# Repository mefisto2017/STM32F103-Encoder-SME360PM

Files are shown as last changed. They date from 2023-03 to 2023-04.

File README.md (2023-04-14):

# STM32F103-Encoder-SME360PM

> __Warning__
 Crystal oscilator pins are not connected, working on the fix!

## About The Project
The code and board schematic were designed to read 4 absolute encoders SME360PM of a 4 wheel independent steering robot and transmit the values through CAN interface. The values are read in continous mode and organized using DMA. The board is based on the STM32F103 blue pill.

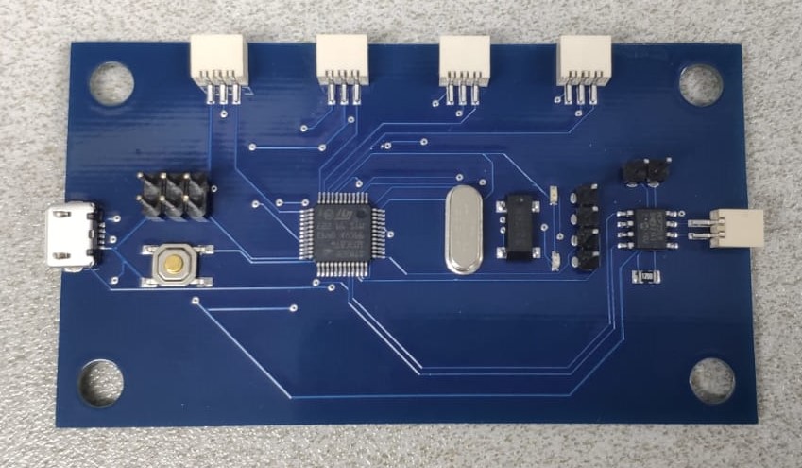
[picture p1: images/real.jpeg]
This is an image


## Getting Started

1. To request the values the following message must be send:
```sh
  [0x01, 0x00, 0x00, 0x00, 0x42, 0x1, 0x00, 0x00, 0x00, 0x00, 0x00, 0x00, 0x00]
```

2. The python script can be use to read and decode the angles 
```sh
  python3 Python_test_code/test.py
```

## Schematic Files
Schematic and gerber were generated on Eagle.

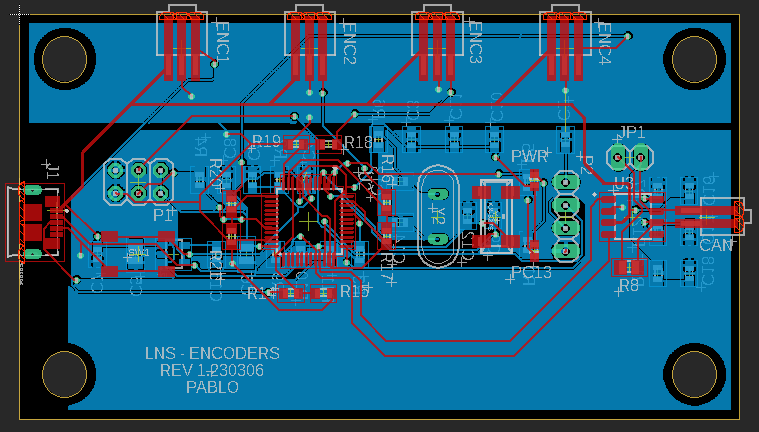
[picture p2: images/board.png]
This is an image


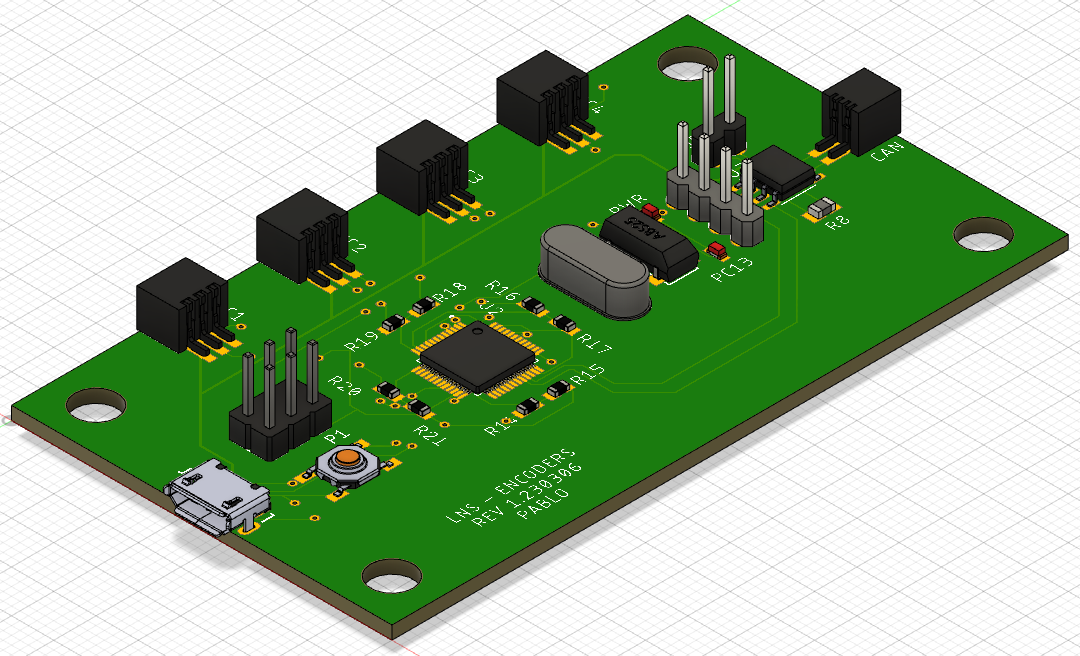
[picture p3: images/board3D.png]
This is an image


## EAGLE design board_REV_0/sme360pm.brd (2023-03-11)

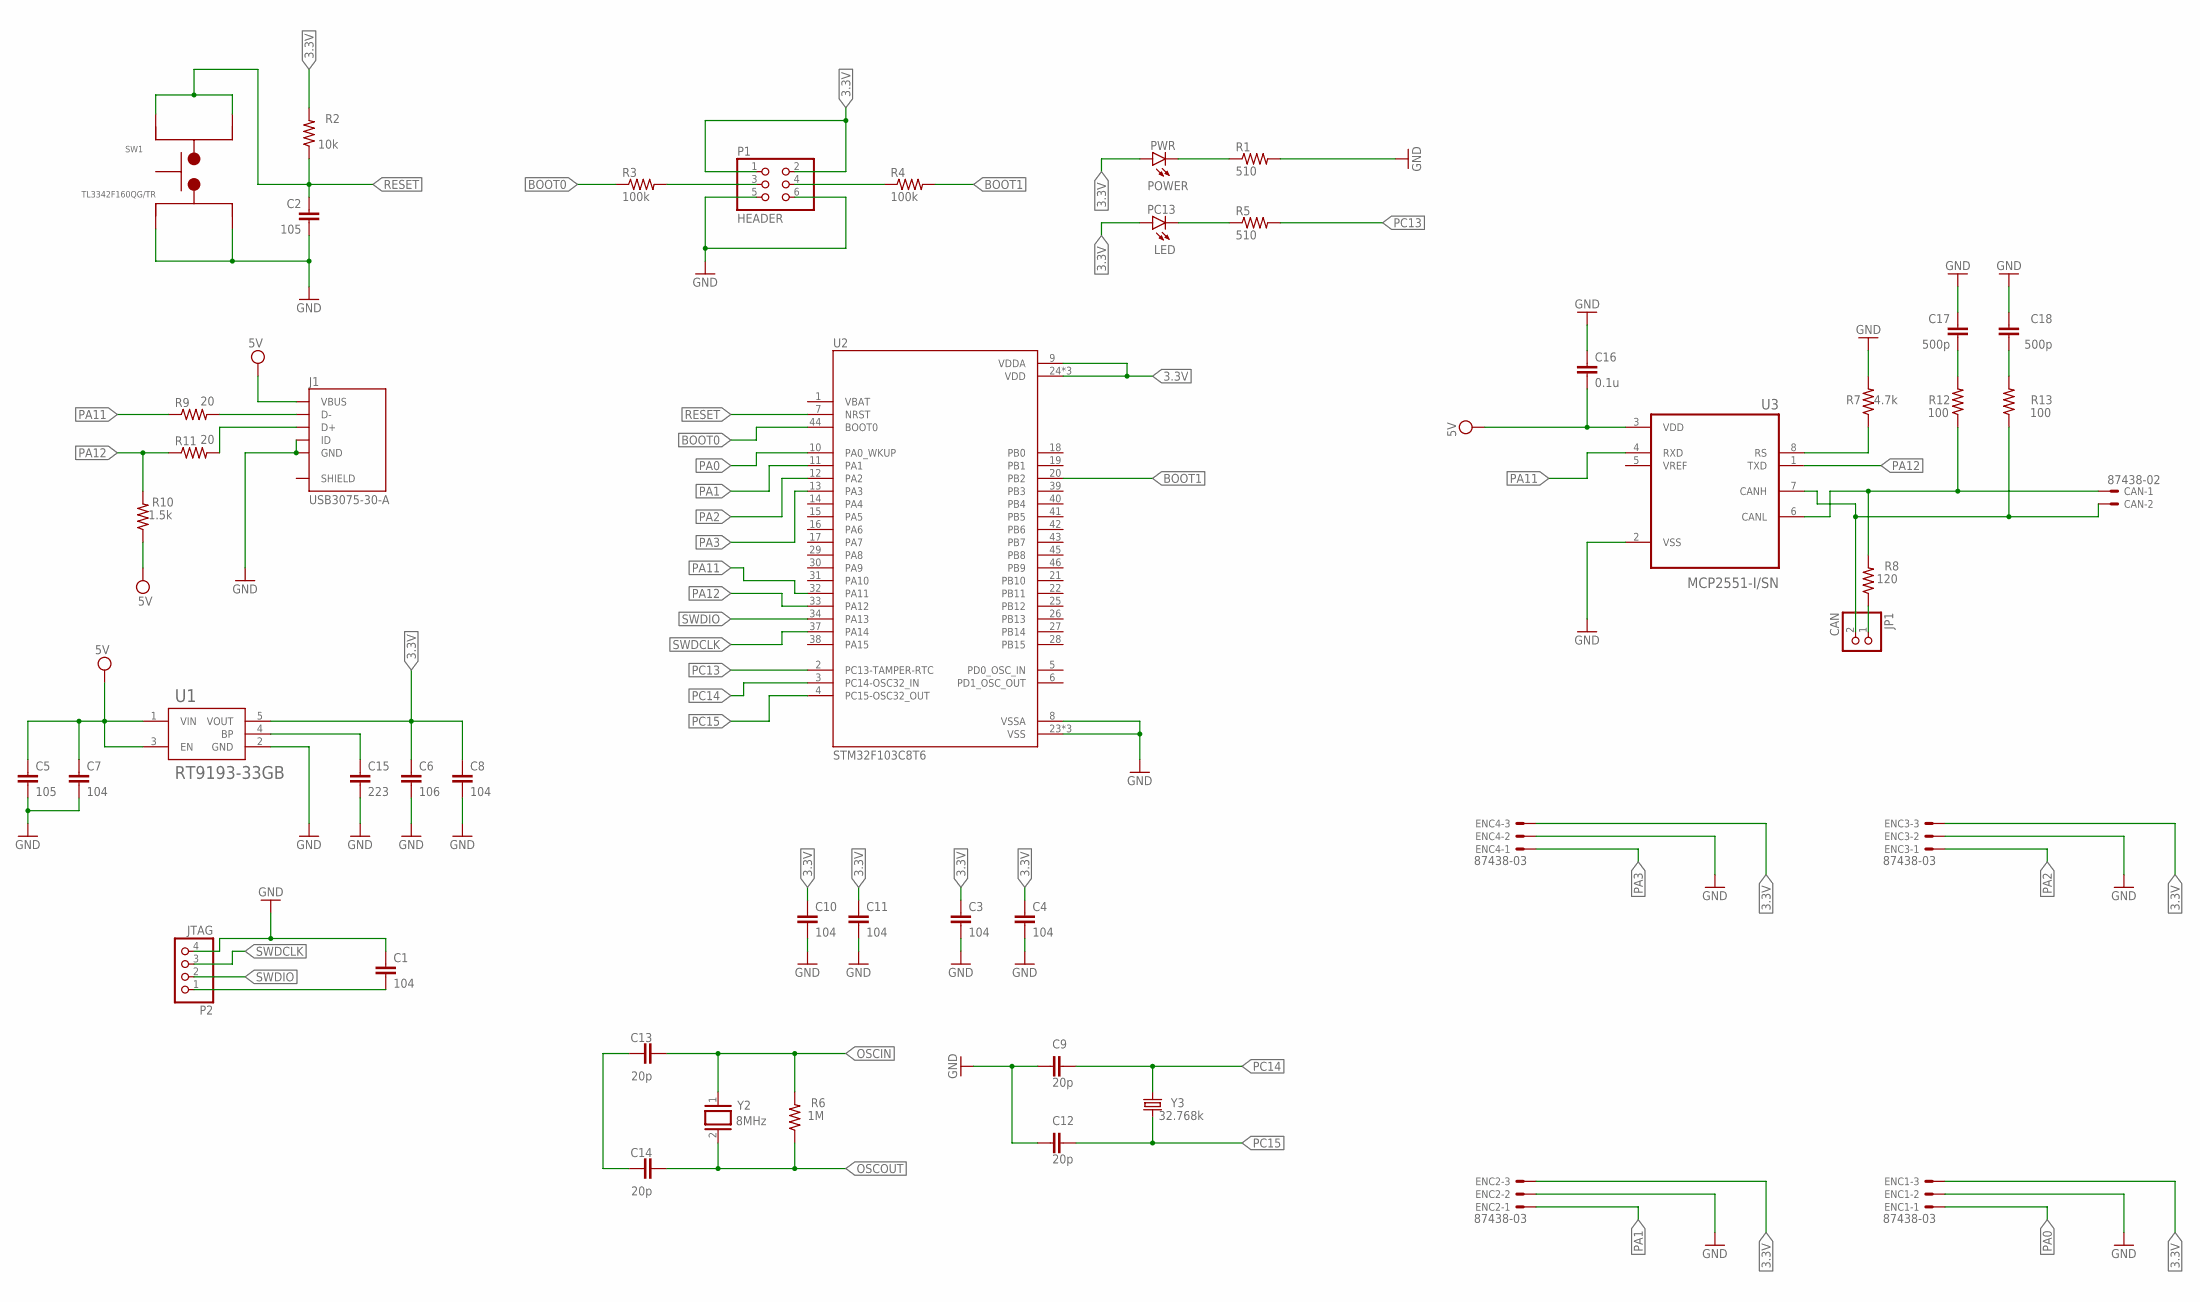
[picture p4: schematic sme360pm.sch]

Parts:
C1, C3, C4, C7, C8, C10, C11: 104; C0603
C2: 105; C0603
C5: 105; C0805
C6: 106; C0805
C9, C12, C13, C14: 20p; C0603
C15: 223; C0603
C16: 0.1u; C0603
C17, C18: 500p; C0603
CAN: 87438-02
ENC1, ENC2, ENC3, ENC4: 87438-03
J1: USB3075-30-A; GCT_USB3075-30-A
JP1: CAN; 1X02
P1: HEADER; 2X03
P2: JTAG; 1X04
PC13: LED; CHIP-LED0603
PWR: POWER; CHIP-LED0603
R1, R5: 510; R0603
R2: 10k; R0603
R3, R4: 100k; R0603
R6: 1M; R0603
R7: 4.7k; R0603
R8: 120; R0805
R9, R11: 20; R0603
R10: 1.5k; R0603
R12, R13: 100; R0603
SW1: TL3342F160QG/TR; SW_TL3342F160QG/TR
U1: RT9193-33GB; SOT94P279X129-5N
U2: STM32F103C8T6; QFP50P900X900X160-48N
U3: MCP2551-I/SN; SOIC127P599X175-8N
Y2: 8MHz; QS
Y3: 32.768k; 8.2X3.8

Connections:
3.3V: C3.1, C4.1, C6.1, C8.1, C10.1, C11.1, ENC1.3, ENC2.3, ENC3.3, ENC4.3, P1.1, P1.2, PC13.A, PWR.A, R2.2, U1.5 (VOUT), U2.9 (VDDA), U2.24 (VDD), U2.36 (VDD), U2.48 (VDD)
BOOT0: R3.1, U2.44 (BOOT0)
BOOT1: R4.2, U2.20 (PB2)
GND: C1.1, C2.1, C3.2, C4.2, C5.2, C6.2, C7.2, C8.2, C9.2, C10.2, C11.2, C12.2, C15.2, C16.1, C17.2, C18.2, ENC1.2, ENC2.2, ENC3.2, ENC4.2, J1.4 (ID), J1.5 (GND), P1.5, P1.6, P2.4, R1.2, R7.2, SW1.1, SW1.2, U1.2 (GND), U2.8 (VSSA), U2.23 (VSS), U2.35 (VSS), U2.47 (VSS), U3.2 (VSS)
unnamed: J1.2 (D-), R9.2
unnamed: J1.3 (D+), R11.2
unnamed: PWR.C, R1.1
unnamed: C15.1, U1.4 (BP)
unnamed: C13.1, C14.1
unnamed: PC13.C, R5.1
unnamed: C1.2, P2.1
unnamed: P1.3, R3.2
unnamed: P1.4, R4.1
unnamed: R7.1, U3.8 (RS)
unnamed: CAN.1, R8.2, R12.1, U3.6 (CANL)
unnamed: JP1.1, R8.1
unnamed: CAN.2, JP1.2, R13.1, U3.7 (CANH)
unnamed: C17.1, R12.2
unnamed: C18.1, R13.2
OSCIN: C13.2, R6.2, Y2.1
OSCOUT: C14.2, R6.1, Y2.2
PA0: ENC1.1, U2.10 (PA0_WKUP)
PA1: ENC2.1, U2.11 (PA1)
PA2: ENC3.1, U2.12 (PA2)
PA3: ENC4.1, U2.13 (PA3)
PA11: R9.1, U2.32 (PA11), U3.4 (RXD)
PA12: R10.2, R11.1, U2.33 (PA12), U3.1 (TXD)
PC13: R5.2, U2.2 (PC13-TAMPER-RTC)
PC14: C9.1, U2.3 (PC14-OSC32_IN), Y3.4 (2)
PC15: C12.1, U2.4 (PC15-OSC32_OUT), Y3.1
RESET: C2.2, R2.1, SW1.3, SW1.4, U2.7 (NRST)
SWDCLK: P2.3, U2.37 (PA14)
SWDIO: P2.2, U2.34 (PA13)
VCC: C5.1, C7.1, C16.2, J1.1 (VBUS), R10.1, U1.1 (VIN), U1.3 (EN), U3.3 (VDD)

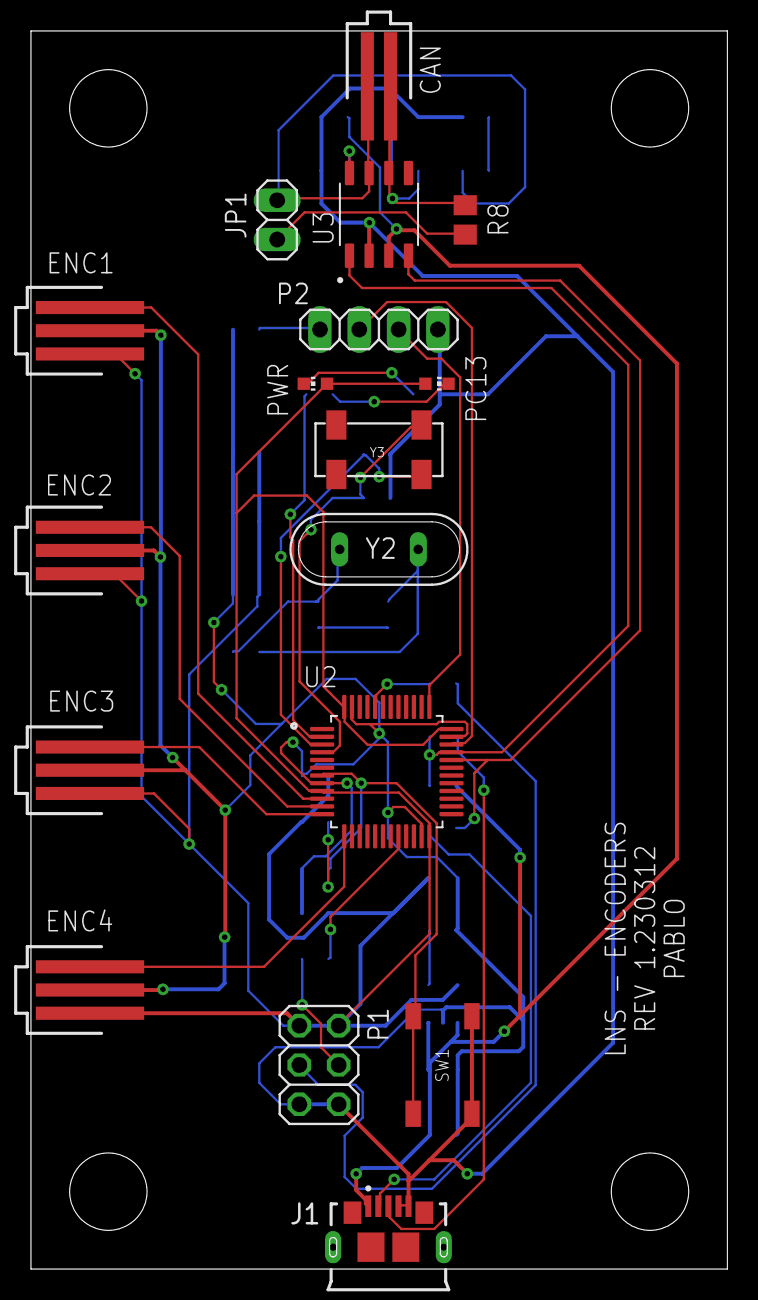
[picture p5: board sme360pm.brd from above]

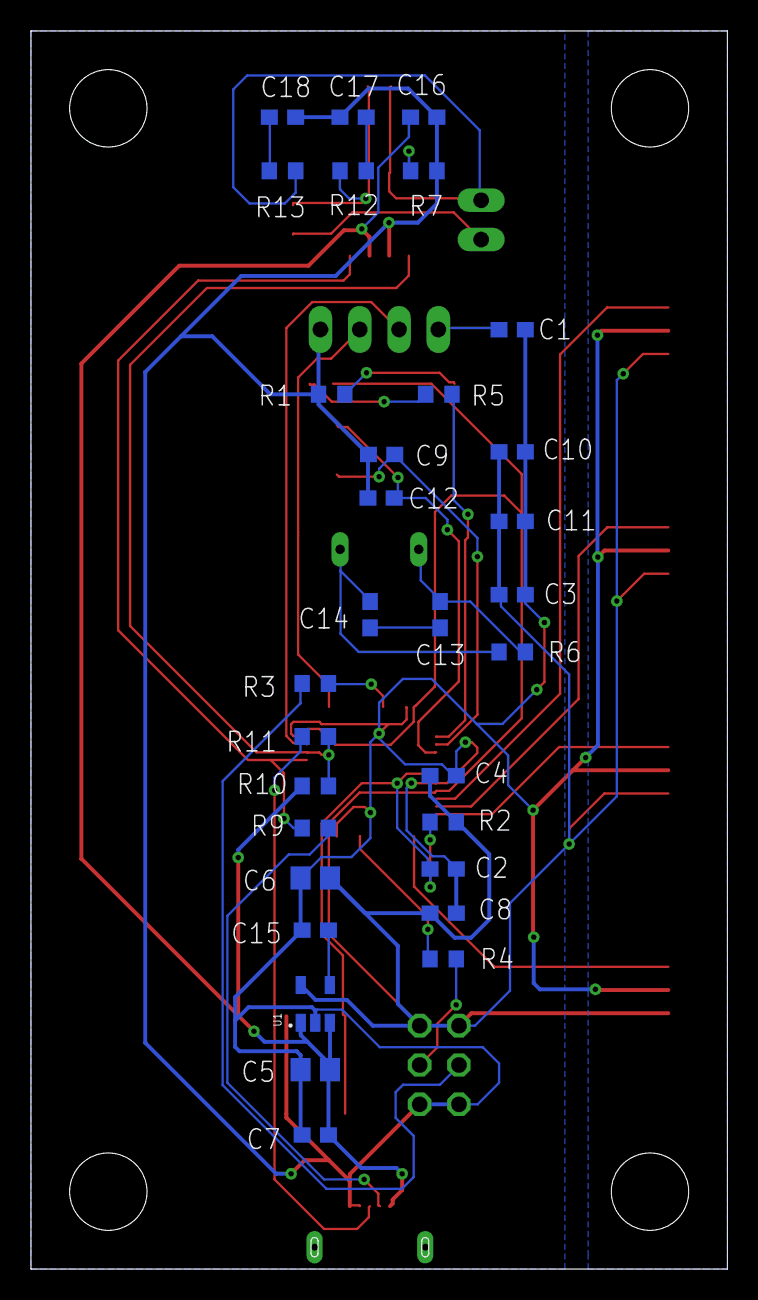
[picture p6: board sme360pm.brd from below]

Board: 2 copper layers, 45.0 x 80.0 mm, 48 parts (31 on the bottom side), 34 nets.

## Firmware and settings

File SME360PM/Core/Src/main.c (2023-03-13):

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
/* Includes ------------------------------------------------------------------*/
#include "main.h"

CAN_HandleTypeDef hcan;
ADC_HandleTypeDef hadc1;
DMA_HandleTypeDef hdma_adc1;

void SystemClock_Config(void);
static void MX_GPIO_Init(void);
static void MX_CAN_Init(void);
static void MX_DMA_Init(void);
static void MX_ADC1_Init(void);
/* USER CODE BEGIN 0 */

// ~~~~~~~~~~~~~~~~~~  CAN VARIABLES  ~~~~~~~~~~~~~~~~~~
CAN_TxHeaderTypeDef TxHeader;
CAN_RxHeaderTypeDef RxHeader;

uint8_t TxData[8];
uint8_t RxData[8];

uint32_t TxMailbox;

int datacheck = 0;

// ~~~~~~~~~~~~~~~~~~  ADC VARIABLES  ~~~~~~~~~~~~~~~~~~
volatile uint16_t adcResultsDMA[4];
const int adcChannelCount = sizeof(adcResultsDMA) / sizeof(adcResultsDMA[0]);
volatile int adcConversionComplete = 0;


// ~~~~~~~~~~~~~~~~~~  CAN INTERRUPT  ~~~~~~~~~~~~~~~~~~
void HAL_CAN_RxFifo1MsgPendingCallback(CAN_HandleTypeDef *hcan)
{
	HAL_CAN_GetRxMessage(hcan, CAN_RX_FIFO1, &RxHeader, RxData);
	if (RxHeader.DLC == 1 && RxData[0] == 1) // Check if only 1 byte of data && if it is requesting data
	{
		datacheck = 1;
	}
}

// ~~~~~~~~~~~~~~~~~~  ADC INTERRUPT  ~~~~~~~~~~~~~~~~~~
void HAL_ADC_ConvCpltCallback(ADC_HandleTypeDef *hadc)
{
	adcConversionComplete = 1;
}

// ~~~~~~~~~~~~~~~~~~  TRANSFORM INT TO BYTE  ~~~~~~~~~~~~~~~~~~
void intTobyte(void)
{
	for (int i =0; i < 4; i++)
	{
		TxData[2*i] = (adcResultsDMA[i] >> 8) & 0xff; // big byte
		TxData[2*i+1] = adcResultsDMA[i] & 0xff;      // little byte
	}

}

/* USER CODE END 0 */

/**
  * @brief  The application entry point.
  * @retval int
  */
int main(void)
{
  /* MCU Configuration--------------------------------------------------------*/

  /* Reset of all peripherals, Initializes the Flash interface and the Systick. */
  HAL_Init();

  /* Configure the system clock */
  SystemClock_Config();

  /* Initialize all configured peripherals */
  MX_GPIO_Init();
  MX_CAN_Init();
  MX_DMA_Init();
  MX_ADC1_Init();
  /* USER CODE BEGIN 2 */

  HAL_CAN_Start(&hcan);

  // Activate the notification
  HAL_CAN_ActivateNotification(&hcan, CAN_IT_RX_FIFO1_MSG_PENDING);


  TxHeader.DLC = 8;  // data length
  TxHeader.IDE = CAN_ID_STD;
  TxHeader.RTR = CAN_RTR_DATA;
  TxHeader.StdId = 0x67;  // ID 103

    // ADC Calibration
    while(HAL_ADCEx_Calibration_Start(&hadc1) != HAL_OK);

  /* USER CODE END 2 */

  /* Infinite loop */
  /* USER CODE BEGIN WHILE */
  while (1)
  {
    /* USER CODE END WHILE */

    /* USER CODE BEGIN 3 */

	  HAL_ADC_Start_DMA(&hadc1, (uint32_t*)&adcResultsDMA, adcChannelCount);
	  while (adcConversionComplete == 0)
	  {

	  }
	  intTobyte();
	  adcConversionComplete = 0;

	  if (datacheck)
	  {
		  HAL_CAN_AddTxMessage(&hcan, &TxHeader, TxData, &TxMailbox);
		  HAL_GPIO_TogglePin(GPIOC, GPIO_PIN_13);
		  datacheck = 0;
	  }
  }
  /* USER CODE END 3 */
}

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
/**
  * Enable DMA controller clock
  */
static void MX_DMA_Init(void)
{

  /* DMA controller clock enable */
  __HAL_RCC_DMA1_CLK_ENABLE();

  /* DMA interrupt init */
  /* DMA1_Channel1_IRQn interrupt configuration */
  HAL_NVIC_SetPriority(DMA1_Channel1_IRQn, 0, 0);
  HAL_NVIC_EnableIRQ(DMA1_Channel1_IRQn);

}


/**
  * @brief ADC1 Initialization Function
  * @param None
  * @retval None
  */
static void MX_ADC1_Init(void)
{

  ADC_ChannelConfTypeDef sConfig = {0};

  /** Common config
  */
  hadc1.Instance = ADC1;
  hadc1.Init.ScanConvMode = ADC_SCAN_ENABLE;
  hadc1.Init.ContinuousConvMode = DISABLE;
  hadc1.Init.DiscontinuousConvMode = DISABLE;
  hadc1.Init.ExternalTrigConv = ADC_SOFTWARE_START;
  hadc1.Init.DataAlign = ADC_DATAALIGN_RIGHT;
  hadc1.Init.NbrOfConversion = 4;
  if (HAL_ADC_Init(&hadc1) != HAL_OK)
  {
    Error_Handler();
  }

  /** Configure Regular Channel
  */
  sConfig.Channel = ADC_CHANNEL_0;
  sConfig.Rank = ADC_REGULAR_RANK_1;
  sConfig.SamplingTime = ADC_SAMPLETIME_28CYCLES_5;
  if (HAL_ADC_ConfigChannel(&hadc1, &sConfig) != HAL_OK)
  {
    Error_Handler();
  }

  /** Configure Regular Channel
  */
  sConfig.Channel = ADC_CHANNEL_1;
  sConfig.Rank = ADC_REGULAR_RANK_2;
  sConfig.SamplingTime = ADC_SAMPLETIME_28CYCLES_5;
  if (HAL_ADC_ConfigChannel(&hadc1, &sConfig) != HAL_OK)
  {
    Error_Handler();
  }

  /** Configure Regular Channel
  */
  sConfig.Channel = ADC_CHANNEL_2;
  sConfig.Rank = ADC_REGULAR_RANK_3;
  sConfig.SamplingTime = ADC_SAMPLETIME_28CYCLES_5;
  if (HAL_ADC_ConfigChannel(&hadc1, &sConfig) != HAL_OK)
  {
    Error_Handler();
  }

  /** Configure Regular Channel
  */
  sConfig.Channel = ADC_CHANNEL_3;
  sConfig.Rank = ADC_REGULAR_RANK_4;
  sConfig.SamplingTime = ADC_SAMPLETIME_28CYCLES_5;
  if (HAL_ADC_ConfigChannel(&hadc1, &sConfig) != HAL_OK)
  {
    Error_Handler();
  }
}

/**
  * @brief  This function is executed in case of error occurrence.
  * @retval None
  */
void Error_Handler(void)
{
  /* USER CODE BEGIN Error_Handler_Debug */
  /* User can add his own implementation to report the HAL error return state */
  __disable_irq();
  while (1)
  {
  }
  /* USER CODE END Error_Handler_Debug */
}

#ifdef  USE_FULL_ASSERT
/**
  * @brief  Reports the name of the source file and the source line number
  *         where the assert_param error has occurred.
  * @param  file: pointer to the source file name
  * @param  line: assert_param error line source number
  * @retval None
  */
void assert_failed(uint8_t *file, uint32_t line)
{
  /* USER CODE BEGIN 6 */
  /* User can add his own implementation to report the file name and line number,
     ex: printf("Wrong parameters value: file %s on line %d\r\n", file, line) */
  /* USER CODE END 6 */
}
#endif /* USE_FULL_ASSERT */

/************************ (C) COPYRIGHT STMicroelectronics *****END OF FILE****/

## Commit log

2023-03-02 ADC DMA
2023-03-04 Board eagle files
    [sme360pm.brd, sme360pm.sch]
2023-03-06 Updated board
    [sme360pm.brd, sme360pm.sch]
2023-03-09 check communication and values
    using socket and CANET200
2023-03-09 STM32 code
2023-03-09 Fix problem values coupled
    [main.c]
2023-03-11 Removed voltage divider
    [sme360pm.brd, sme360pm.sch]
2023-03-13 Added adc prescaler value
2023-04-02 gerber files
    [copper_bottom.gbr, copper_top.gbr, drill_1_16.xln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]

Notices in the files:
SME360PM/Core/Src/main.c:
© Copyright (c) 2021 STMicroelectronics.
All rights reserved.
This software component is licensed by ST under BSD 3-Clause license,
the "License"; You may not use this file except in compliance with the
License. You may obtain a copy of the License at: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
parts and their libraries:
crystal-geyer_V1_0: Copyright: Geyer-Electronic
